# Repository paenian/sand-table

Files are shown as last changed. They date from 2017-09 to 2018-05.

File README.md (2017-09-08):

# sand-table

I'd like to make my own sand drawing table.

Main desired features:
G-code driven
hand-wheel drive as well

The initial drive idea is similar to the Maslow CNC, which is cable-driven polar
robot with two stepper motors.  Instead of using weights, I'll use constant-
force springs to keep the main carriage taut and driving.  The carriage will be
under the sand table, and moving a neodidlium magnet to drag a steel ball bearing
around.

I'd like it to be usable as a table, but also interactive - the easy way is a
handheld magnet puck that can steal the ball bearing and be used to draw directly;
also would like some direct-input hand wheels, and the ability to load new
drawings easily.  A good end-goal would be a self-hosted website where random
photos could be dropped, traced, parsed to gcode and drawn.

Most parts will be 3D printed.

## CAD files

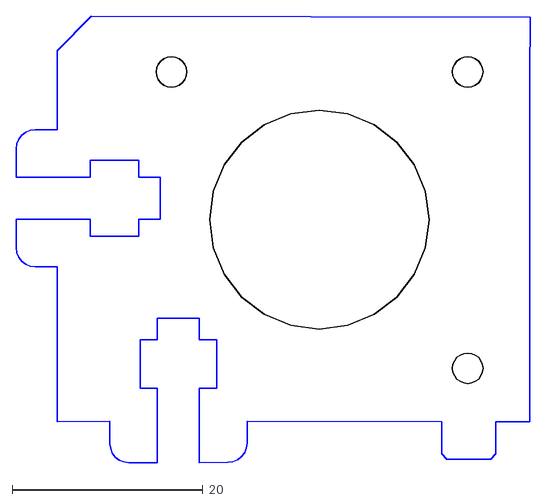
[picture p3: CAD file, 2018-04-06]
gcodes/y_motor_mount.dxf
53.8 x 46.7

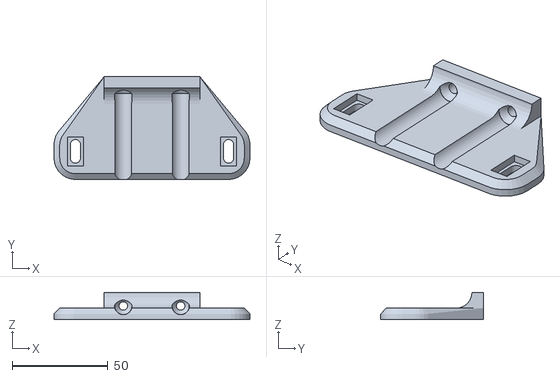
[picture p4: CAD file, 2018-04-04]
hardware/crossbot_stls/mount_brace.stl
102.4 x 53.6 x 14.2

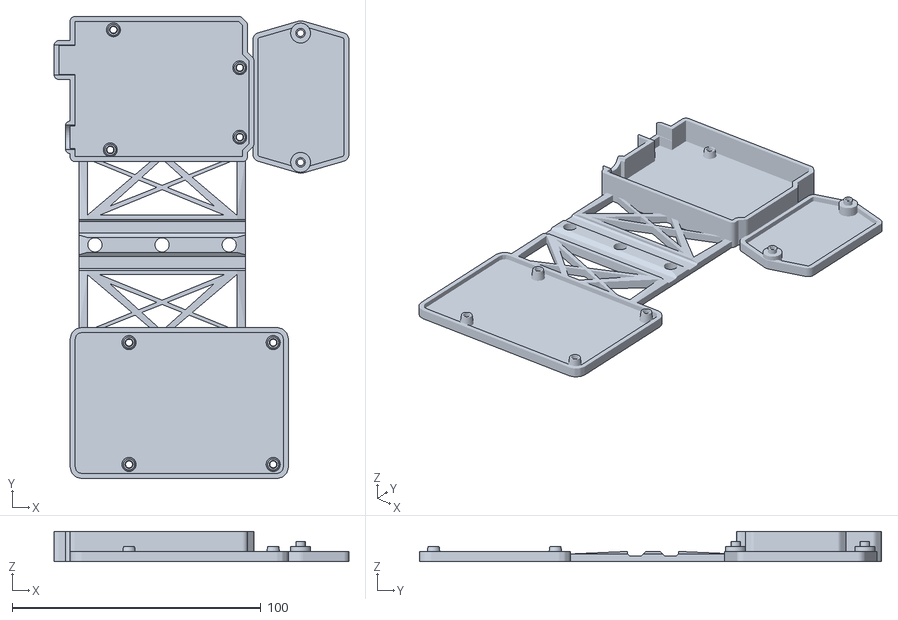
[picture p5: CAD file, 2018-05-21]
hardware/electronics_plate.stl
118.7 x 185.9 x 12.1

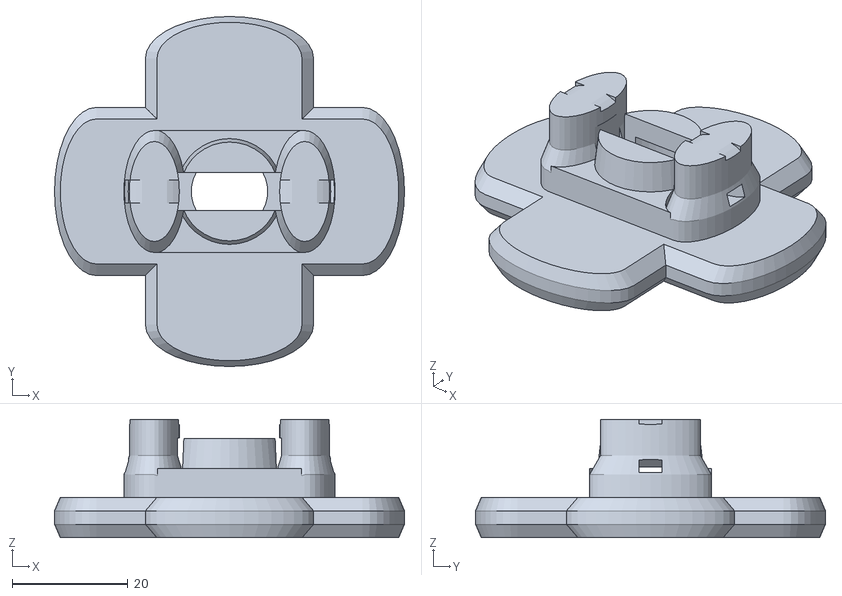
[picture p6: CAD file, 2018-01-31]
hardware/gravity_stls/magnet_mount_1-2.stl
60.5 x 60.5 x 20.5

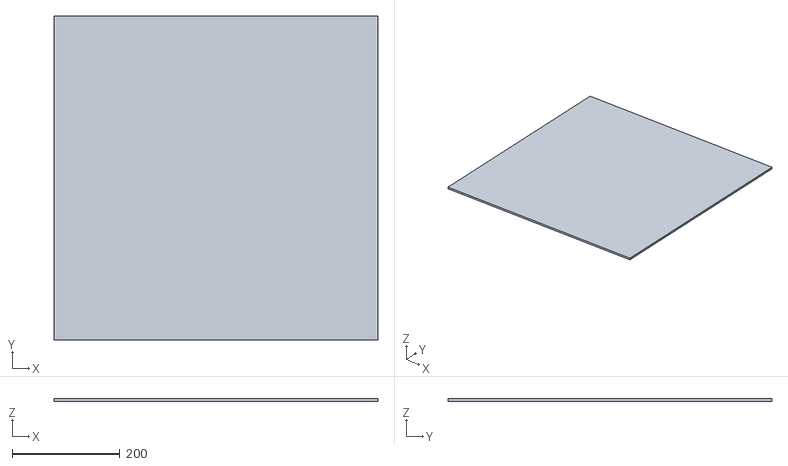
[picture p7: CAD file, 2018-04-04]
gcodes/clear.stl
600.0 x 600.0 x 5.00

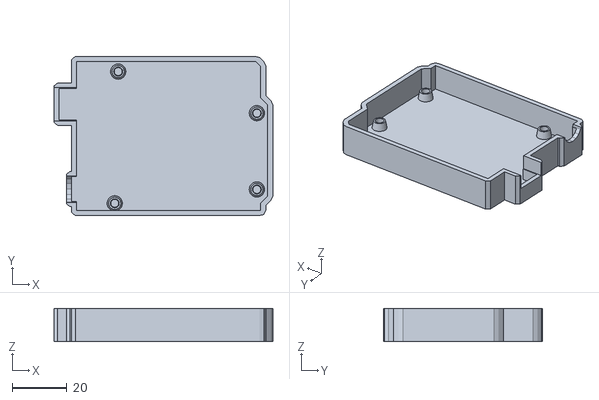
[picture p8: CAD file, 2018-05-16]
hardware/arduino_sled.stl
80.2 x 58.3 x 12.1

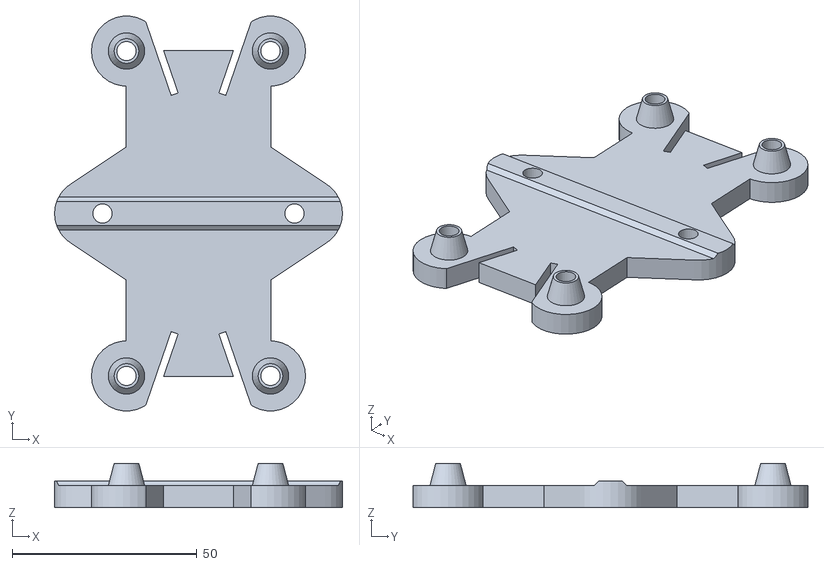
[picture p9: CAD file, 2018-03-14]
hardware/crossbot_stls/beam_carriage.stl
78.0 x 106.9 x 12.0

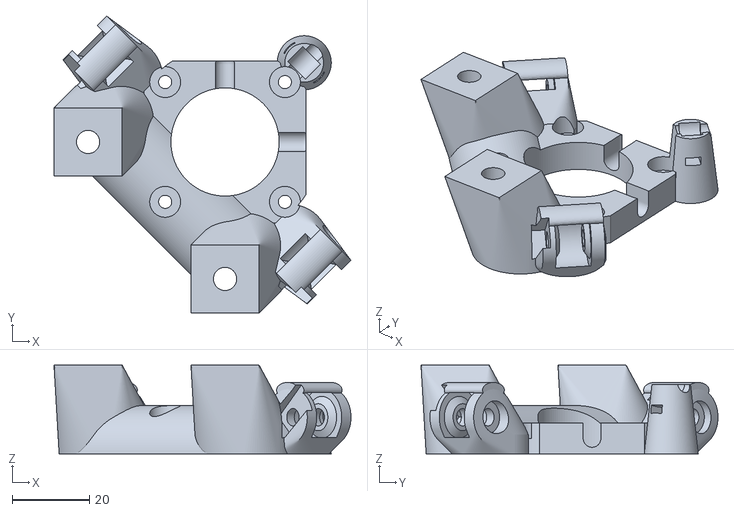
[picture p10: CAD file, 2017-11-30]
hardware/gravity_stls/gravity_leg_motor.stl
76.9 x 76.9 x 23.0

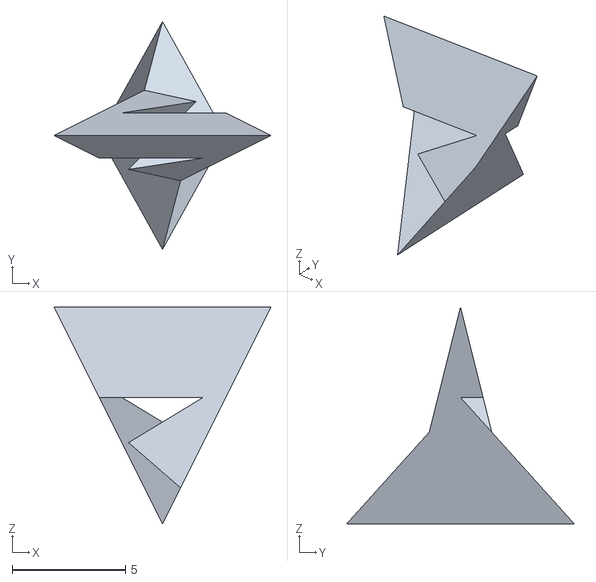
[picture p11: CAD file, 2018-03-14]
software/inkscape/share/extensions/Poly3DObjects/szilassi.obj
9.60 x 10.1 x 9.60

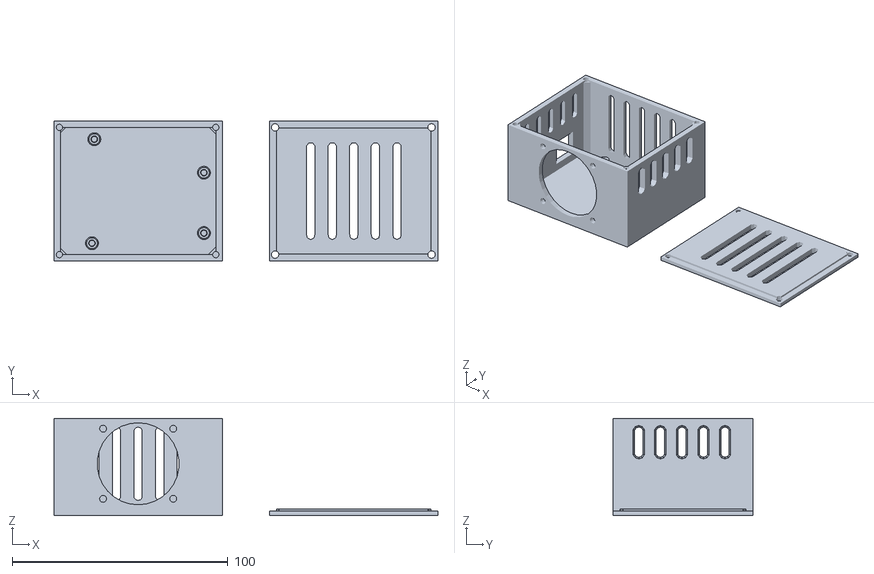
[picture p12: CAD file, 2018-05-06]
hardware/arduino_mount.stl
178.0 x 65.0 x 45.0

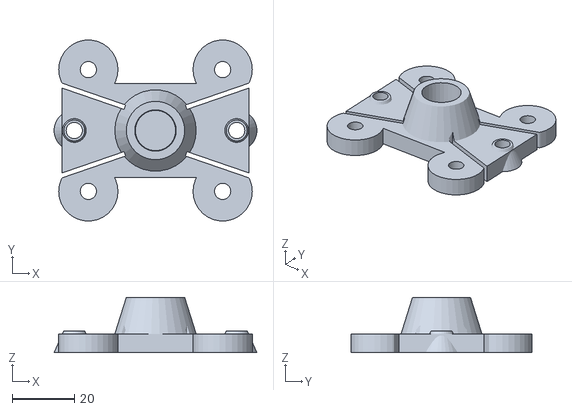
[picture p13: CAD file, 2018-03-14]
hardware/crossbot_stls/magnet_carriage.stl
65.0 x 57.9 x 17.7

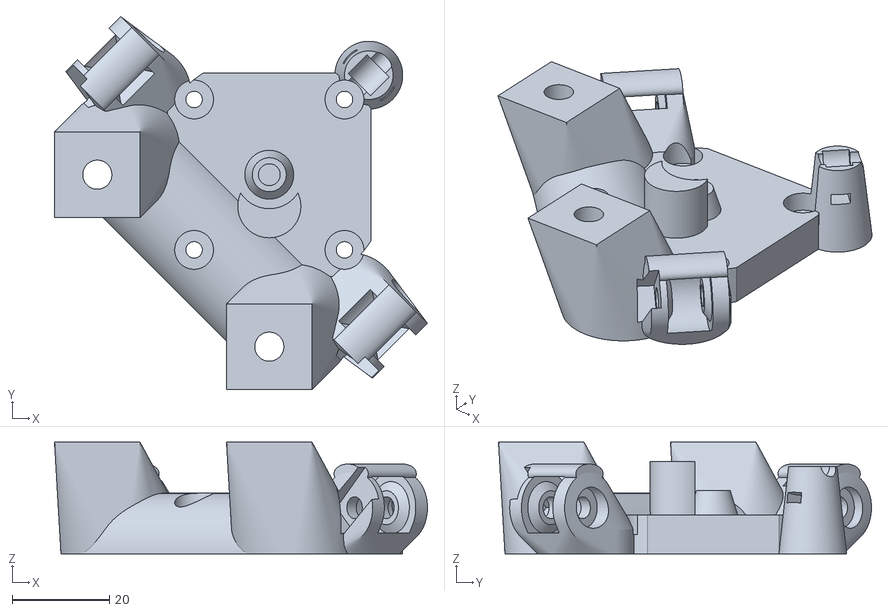
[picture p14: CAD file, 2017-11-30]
hardware/gravity_stls/gravity_leg_idler.stl
76.9 x 76.9 x 23.0

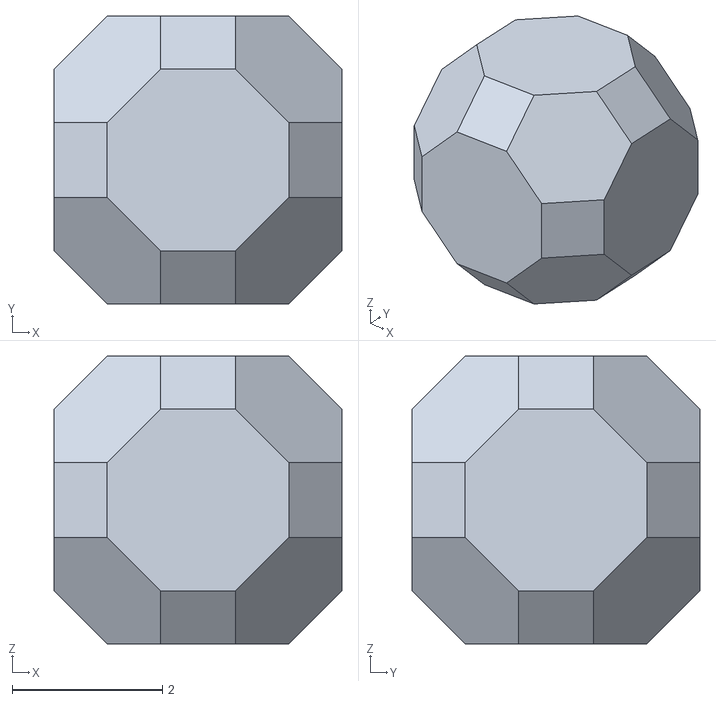
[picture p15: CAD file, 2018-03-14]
software/inkscape/share/extensions/Poly3DObjects/great_rhombicuboct.obj
3.83 x 3.83 x 3.83

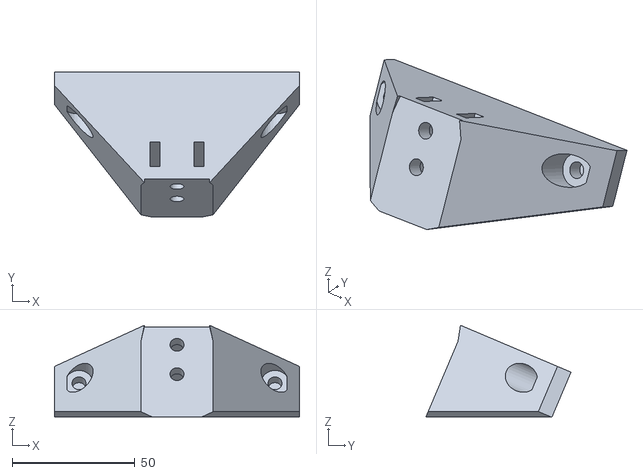
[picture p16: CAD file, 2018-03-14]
hardware/crossbot_stls/base_beam_mount_motor.stl
100.0 x 59.2 x 37.3

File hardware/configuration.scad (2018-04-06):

in = 25.4;
beam = 20;

wall = 6;   //beefy carriages


spacer_height = 6; 

//this is for the big v-wheels
wheel_thick = 10.23;
wheel_rad = 23.9/2;
wheel_eff_rad = 19/2;   //radius sticking out of the v-slot

/*
//this is for the mini v-wheels
wheel_thick = 8.8;
wheel_rad = 15.23/2;
wheel_eff_rad = 11/2;   //radius sticking out of the v-slot
*/

main_beam_length = 500;
cross_beam_length = 500;

//height of the stack!
//the magnet is at zero, so nothing sticks up above the Z plane.
magnet_height = in/2;
magnet_rad = in/4;
carriage_clearance = wall + (wheel_thick/2+spacer_height)-beam/2;
echo(carriage_clearance);
                //magnet         this beam  X carriage             x beam
y_beam_height = -magnet_height - beam/2 -   carriage_clearance -   beam - carriage_clearance;
x_beam_height = -magnet_height - beam/2 - carriage_clearance;
magnet_carriage_height = -magnet_height-wall;
beam_carriage_height = -magnet_height-carriage_clearance-beam-wall;

//idler RANDOM NUMBERS
idler_rad = 9;
idler_flange_rad = 11;
idler_flange_thick = 1.5;
idler_height = 12;

//pulley RANDOM NUMBERS
pulley_rad = 9;
pulley_flange_rad = 11;
pulley_flange_thick = 1.5;
pulley_base_rad = 12;
pulley_base_thick = 10;
pulley_height = 18;


//screws et al
m5_rad = 5/2+.15;
m5_nut_rad = 8.79/2+.25;

belt_thick = 1.5;
belt_height = 6;




module beam(length = 20, center=true){
    beam_wall = 1.8;
    beam_center_rad = 4.2/2+.1;
    
    difference(){
        cube([beam, beam, length], center=center);
        
        //center hole
        translate([0,0,-.1]) cylinder(r=beam_center_rad, h=length+1, center=center, $fs=1);
        
        //inside
        translate([0,0,-.1]) difference(){
            cube([beam-beam_wall*2,beam-beam_wall*2,length+1], center=center);
            
            //center
            cube([7,7,length+2], center=true);
            //cross walls
            for(i=[45:90:179]) rotate([0,0,i]) {
                cube([1.5, 19.75, length+1], center=true);
            }
            
            //corners
            for(i=[0:90:359]) rotate([0,0,i]) translate([beam/2, beam/2,0]) {
                difference(){
                    cube([(1.8+1.07+1.75)*2, (1.8+1.07+1.75)*2, length+1], center=true);
                    cube([(1.8+1.75)*2, (1.8+1.75)*2, length+1], center=true);
                }
            }
        }
        
        //v slot channel
        for(i=[0:90:359]) rotate([0,0,i]) translate([beam/2, 0,0]) {
            rotate([0,0,45]) cube([6.5,6.5,length+2], center=true);
        }
        
        //chamfer the corners
        for(i=[0:90:359]) rotate([0,0,i]) translate([beam/2, beam/2,0]) {
            rotate([0,0,45]) cube([1,1,length+2], center=true);
        }
    }
}

module pulley(solid = 1){
    if(solid == 1){
        difference(){
            union(){
                cylinder(r=pulley_rad, h=pulley_height, center=true);
                translate([0,0,pulley_height/2-pulley_flange_thick/2])
                    cylinder(r=pulley_flange_rad, h=pulley_flange_thick, center=true);
            
                translate([0,0,-pulley_height/2+pulley_base_thick/2]) cylinder(r=pulley_base_rad, h=pulley_base_thick, center=true);
            }
        
            cylinder(r=m5_rad, h=pulley_height+1, center=true);
        }
    }else{
        cylinder(r=m5_rad, h=idler_height*5, center=true);
    }
}

module idler(solid = 1){
    if(solid == 1){
        difference(){
            union(){
                cylinder(r=idler_rad, h=idler_height, center=true);
                for(i=[0,1]) mirror([0,0,i]) translate([0,0,idler_height/2-idler_flange_thick/2]){
                    cylinder(r=idler_flange_rad, h=idler_flange_thick, center=true);
                }
            
                //ghost in some belts
                for(i=[0,1]) mirror([0,i,0]) translate([0,idler_rad+belt_thick/2,0]){
                    %cube([200,belt_thick,belt_height], center=true);
                }
            }
        
            cylinder(r=m5_rad, h=idler_height+1, center=true);
        }
    }else{
        cylinder(r=m5_rad, h=idler_height*5, center=true);
    }
}

module wheel(solid = 1){
    if(solid == 1){
        difference(){
            hull(){
                cylinder(r=wheel_rad, h=wheel_thick/3, center=true);
                cylinder(r=wheel_rad-wheel_thick/3, h=wheel_thick, center=true);
            }
        
            cylinder(r=m5_rad, h=idler_height+1, center=true);
        }
    }else{
        cylinder(r=m5_rad, h=idler_height*3, center=true);
    }
}

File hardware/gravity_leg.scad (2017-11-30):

in = 25.4;

fs = .3;

$fa = 3;    //sets the angle low enough that $fs is dominant
$fs = fs;    //the smallest edge is this long - with a .4mm nozzle, the facets should be undetectable for printing, but we keep it high for modeling faster.

motor_w = 42;
motor_h = 30;
motor_rad = 50/2;
motor_bump_rad = 26/2+1;
motor_bump_height = 2;
motor_shaft_rad = 4/2+.25;
motor_shaft_len = 22;
motor_screw_sep = 31;
motor_screw_rad = 3.4/2;
motor_screw_cap_rad = 8/2;
motor_screw_len = 10;

pulley_rad = 40/(2*3.14159)+.25; 
pulley_height = 19;
pulley_base_height = 7;
pulley_base_rad = 11-.25;
pulley_nut_rad = 7;
pulley_nut_thick = 3;

hairpin_base_width = 50;
hairpin_base_height = 127;
hairpin_base_thick = 3;
hairpin_leg_rad = 3/8*in/2;
hairpin_x_offset = 88;
hairpin_y_offset = 18;
hairpin_leg_extend = hairpin_base_width;
hairpin_hole_inset = 9;
hairpin_hole_1 = in*1.75;
hairpin_hole_2 = hairpin_base_height-hairpin_hole_inset;
hairpin_hole_rad = 5/2;
hairpin_hole_cap_rad = 11/2;

v_pulley_thick = 6;
v_pulley_rad = 9/2;
v_pulley_center_rad = 7/2;
v_pulley_flange_rad = 13/2;
v_pulley_edge_thick = 1;

screw_rad = 4/2+.25;
screw_cap_rad = 8/2+.25;
screw_len = 16;
nut_rad = 10/2+.25;
nut_height = 3.25;

spacer_len = 5;
spacer_rad = 6/2+.25;
spacer_wall = 1.125;

string_height = pulley_base_height+(pulley_height-pulley_base_height)/2+motor_bump_height/2;
string_rad = 1;


wall = 4;
motor_offset = -hairpin_base_width/2+hairpin_hole_1;
leg_lift = 23;

%motor();
%translate([-motor_offset,-motor_offset,leg_lift+hairpin_base_thick]) hairpin_leg();


!gravity_leg();
gravity_leg(motor=false);
string_pulley();
*weight_claw(pulley=true);

module weight_claw(h=14, angle = 30, pulley=true){
    weight_rad = in*2/2-.25;
    belt_rad = 11;
    
    difference(){
        union(){
            rotate_extrude(){
                translate([weight_rad,0,0]) circle(r=belt_rad);
            }
            
            if(pulley == true){
                hull(){
                    translate([-weight_rad-belt_rad*0,0,0]) rotate([90,0,0]) cylinder(r=belt_rad, h=screw_len, center=true);
                    translate([-weight_rad-belt_rad*1,0,0]) scale([1,1,1.4]) rotate([90,0,0]) cylinder(r=v_pulley_rad+1, h=screw_len, center=true);
                }
            }
        }
        
        
        sphere(r=weight_rad);
        
        //cut out a chunk
        difference(){
            for(i=[angle/2,-angle/2]) rotate([0,0,i-45]) translate([0,0,-50]) cube([100,100,100]);
            
            for(i=[angle/2,-90-angle/2]) rotate([0,0,i-45+90]) translate([weight_rad,0,0]) sphere(r=belt_rad);
        }
        
        //add the pulley
        if(pulley == true){
            translate([-weight_rad-belt_rad*1,0,0]) rotate([90,0,0]) {
                screw_pack(extend = 11);
                v_pulley(solid=-1);
                %v_pulley(solid=1);
                
            }
        }
        
        //flatten top/bottom
        for(i=[0,1]) mirror([0,0,i]) translate([0,0,100+h/2]) cube([200,200,200], center=true);
    }
}

module gravity_leg(height = leg_lift, motor=true, leg=true){
    base_thick = wall+4;
    v_pulley_height = string_height-v_pulley_thick/2+string_rad*2;
    difference(){
        union(){
            //baseplate - everything mounts here
            translate([0,0,wall/2+2]) motor_body(motor_h=base_thick, motor_bump_height = wall*5, bump=motor);
            
            if(motor == false){
                //draw the v-pulley in
                %translate([0,0,v_pulley_height+v_pulley_thick/2]) v_pulley(solid=1);
                
                //add a bump for the pulley to sit on
                cylinder(r1=v_pulley_center_rad+wall, r2=v_pulley_center_rad, h=v_pulley_height);
                
                //and a guide for the string
                difference(){
                    translate([0,-v_pulley_flange_rad,0]) cylinder(r=v_pulley_flange_rad, h=v_pulley_height+v_pulley_thick);
                    cylinder(r=v_pulley_flange_rad+string_rad/2, h=height+1);
                }
            }else{
                //guide for string around the pulley?
            }
            
            //mount it to the leg
            if(leg == true){
                leg_mount(solid=1, h=height, offset = hairpin_hole_1-hairpin_hole_inset);
            }else{
                //todo: spring mount
            }
            
            //mount the weight pulley and attachment
            weight_mount();
            
            //guide for the string - zip tie in a spacer
            guide_spacer(solid=1);
        }
        
        //attach the motor
        motor_holes(motor_h=wall, motor_bump_height = wall*5, bump=motor, shaft=motor);
        
        if(motor == false){
            //mount the pulley
            translate([0,0,8]){
                translate([0,0,-v_pulley_thick+nut_height+.2]) cylinder(r=screw_rad, h=screw_len);
                hull(){
                    translate([0,0,-v_pulley_thick]) cylinder(r1=nut_rad+.25, r2=nut_rad, h=nut_height, $fn=4);
                    translate([0,0,-v_pulley_thick-8]) cylinder(r1=nut_rad+1, r2=nut_rad+.25, h=8.1, $fn=4);
                }
            }
        }
        
        //make some slots so we can actually attach the pulley
        if(motor == true){
            rad = 2.5;
            for(i=[0,90]) rotate([0,0,i]) translate([0,0,base_thick/2]) hull(){
                cylinder(r=rad, h=10);
                sphere(r=rad);
                
                translate([20,0,0]){
                    cylinder(r=rad, h=10);
                    sphere(r=rad);
                }
            }
        }
        
        //mount the weight pulley and attachment
        weight_mount(solid=-1);
        
        //screwholes for the leg mount
        leg_mount(solid=0, h=height, offset = hairpin_hole_1-hairpin_hole_inset);
        
        //guide for the string - zip tie in a spacer
        guide_spacer(solid=0);
    }
}

module weight_mount(solid=1){
    off = motor_screw_sep/2+11;
    
    translate([-pulley_rad/sqrt(2),-pulley_rad/sqrt(2),0])
    for(i=[0,1]) rotate([0,0,45]) mirror([0,i,0]) rotate([0,0,-45]) if(solid==1){
        union(){
            hull(){
                translate([off-5,-off+5,0]) cylinder(r=10, h=wall+1);
                translate([off,-off,string_height-v_pulley_rad]) rotate([0,0,45]) rotate([0,90,0]) {
                    cylinder(r=v_pulley_flange_rad+.75, h=screw_len, center=true);
                    
                }
            }
            translate([off,-off,string_height-v_pulley_rad-1.5]) rotate([0,0,45]) rotate([0,90,0]) translate([-2-v_pulley_flange_rad,0,0])  scale([1,2,1]) rotate([0,0,45]) cylinder(r=2, h=screw_len, center=true);
            
        }
    }else{
        translate([off,-off,string_height-v_pulley_rad]) rotate([0,0,45]) rotate([0,90,0]) {
            screw_pack(extend_nut=true);
            v_pulley(solid=-1);
            %translate([-v_pulley_rad-1,0,0]) rotate([90,0,0]) cylinder(r=string_rad+.1, h=30, center=true);
            %v_pulley(solid=1);
        }
    }
}

module v_pulley(solid=-1, edge=1.5){
    if(solid == 1){
        for(i=[0,1]) mirror([0,0,i]) {
            cylinder(r1=v_pulley_rad, r2=v_pulley_flange_rad, h=v_pulley_thick/2-v_pulley_edge_thick);
            translate([0,0,v_pulley_thick/2-v_pulley_edge_thick]) cylinder(r=v_pulley_flange_rad, h=v_pulley_edge_thick);
        }
    }else{
        difference(){
            cylinder(r=v_pulley_flange_rad+1, h=v_pulley_thick+edge*2.1, center=true);
            for(i=[0,1]) mirror([0,0,i]) translate([0,0,-v_pulley_thick/2-edge*1.1])
                cylinder(r1=v_pulley_center_rad+2, r2=v_pulley_center_rad, h=edge-.125);
        }
    }
    
    
}

module screw_pack(extend = 0, extend_nut=false){
    screw_cap_len = 4;
    cylinder(r=screw_rad, h=screw_len+screw_cap_len, center=true);
    translate([0,0,screw_len/2+extend/2]) cylinder(r=screw_cap_rad, h=screw_cap_len+extend, center=true);
    hull(){
        translate([0,0,-screw_len/2-extend/2]) cylinder(r1=nut_rad+.125, r2=nut_rad, h=screw_cap_len+extend, center=true, $fn=4);
        if(extend_nut == true){
            translate([-5,-5,-screw_len/2-extend/2]) cylinder(r1=nut_rad+.125, r2=nut_rad, h=screw_cap_len+extend, center=true, $fn=4);
        }
    }
}

module guide_spacer(solid=1){
    h = string_height+string_rad*4;
    off = motor_screw_sep/2+5;
    translate([off, off, 0])
    if(solid == 1){
        hull(){
            cylinder(r1=spacer_len+2, r2=spacer_len, h=h);
        }
    }else{
        //spacer
        translate([0,0,h]) rotate([0,0,45]) rotate([0,90,0]) {
            cylinder(r=spacer_rad, h=spacer_len+.5, center=true);
            cylinder(r=spacer_rad-spacer_wall, h=spacer_len*3, center=true);
        }
        
        //zip tie it in
        translate([0,0,h]) rotate([0,0,45]) scale([1,2,1]) rotate([0,90,0]) rotate_extrude(){
            translate([7,0,0]) square([2,4], center=true);
        }
    }
}
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

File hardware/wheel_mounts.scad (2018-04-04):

in = 25.4;

axle_rad = 5/16*in/2+.5;
axle_lift = 4*in;
length = 3*in;

wall = 8;
lip_inset = 2;


rotate([90,0,0]) boat_wheels();
//rotate([90,0,0]) mirror([1,0,0]) boat_wheels();


module boat_wheels(){
    difference(){
        union(){
            //axle
            translate([0,0,axle_lift]){
                rotate([90,0,0]) cylinder(r=axle_rad+wall, h=wall, center=true);
                rotate([90,0,0]) translate([0,0,wall-.1]) cylinder(r1=axle_rad+wall, r2=axle_rad+wall/2, h=wall+.1, center=true);
            }
            
            //attach bar
            hull(){
                rotate([90,0,0]) cylinder(r=axle_rad+wall, h=wall, center=true);
                rotate([90,0,0]) translate([0,0,wall-.1]) cylinder(r1=axle_rad+wall, r2=axle_rad+wall/2, h=wall+.1, center=true);
                
                translate([length,0,0]){
                    rotate([90,0,0]) cylinder(r=axle_rad+wall, h=wall, center=true);
                    rotate([90,0,0]) translate([0,0,wall-.1]) cylinder(r1=axle_rad+wall, r2=axle_rad+wall/2, h=wall+.1, center=true);
                }
            }
            
            //connect up the axle
            hull(){
                translate([0,0,axle_lift]){
                    rotate([90,0,0]) cylinder(r=axle_rad+wall, h=wall, center=true);
                    rotate([90,0,0]) translate([0,0,wall-.1]) cylinder(r1=axle_rad+wall, r2=axle_rad+wall/2, h=wall+.1, center=true);
                }
                
                rotate([90,0,0]) cylinder(r=axle_rad+wall, h=wall, center=true);
                rotate([90,0,0]) translate([0,0,wall-.1]) cylinder(r1=axle_rad+wall, r2=axle_rad+wall/2, h=wall+.1, center=true);
            }
            
            hull(){
                translate([0,0,axle_lift]){
                    rotate([90,0,0]) cylinder(r=axle_rad+wall, h=wall, center=true);
                    rotate([90,0,0]) translate([0,0,wall-.1]) cylinder(r1=axle_rad+wall, r2=axle_rad+wall/2, h=wall+.1, center=true);
                }
                
                translate([length,0,0]) {
                    rotate([90,0,0]) cylinder(r=axle_rad+wall, h=wall, center=true);
                    rotate([90,0,0]) translate([0,0,wall-.1]) cylinder(r1=axle_rad+wall, r2=axle_rad+wall/2, h=wall+.1, center=true);
                }
            }
        }
        
        //axle holder
        translate([0,0,axle_lift]){
            rotate([90,0,0]) cylinder(r=axle_rad, h=50, center=true);
            rotate([90,0,0]) translate([0,0,-wall*1.5]) cylinder(r2=10, r1=20, h=10, $fn=29);
        }
        
        //cut out to attach
        translate([0,wall/2+wall-lip_inset,0]) cube([500,wall*2,(axle_rad+wall*2)*2], center=true);
        
        //some screwholes
        for(i=[0:length/2:length]) translate([i,0,0]) {
            rotate([-90,0,0]) cylinder(r=2.6, h=50, center=true, $fn=29);
            rotate([90,0,0]) translate([0,0,wall/2]) cylinder(r1=2.6, r2=9/2, h=4.1, $fn=29);
            rotate([90,0,0]) translate([0,0,wall/2+4]) cylinder(r=9/2, h=10, $fn=29);
        }
    }
}

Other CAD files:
software/inkscape/share/extensions/Poly3DObjects/rh_axes.obj
hardware/glass_clamp.stl
hardware/gravity_stls/string_pulley.stl
software/inkscape/share/extensions/Poly3DObjects/small_rhombicuboct.obj
hardware/crossbot.scad
hardware/PM_UNO_base_fan_holder.stl
hardware/PM_uno_mount_fan_mod.stl
hardware/cross_idler.stl
hardware/cross_motor.stl
hardware/crossbot_stls/base_beam_mount.stl
hardware/crossbot_stls/double_idler.stl
hardware/crossbot_stls/motor_beam_mount.stl
hardware/crossbot_stls/motor_mount.stl
hardware/crossbot_stls/offset_motor_mount.stl
hardware/electronics_plate.scad
hardware/glass_clamp_base.stl
hardware/glass_clamp_lever.stl
hardware/glass_clamps.scad
hardware/gravity_stls/belt_clamp.stl
hardware/gravity_stls/belt_pulley.stl
hardware/gravity_stls/drill_guide.stl
hardware/gravity_stls/half_in_magnet_mount.stl
hardware/gravity_stls/idler_corner.stl
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

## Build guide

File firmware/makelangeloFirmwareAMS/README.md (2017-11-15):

Testing with the Makelangelo firmware on the Adafruit motor shield.

Couldn't find documentation...

##MCODES
M17: Engage motors
M18: Disengage motors
M100: Show Help
M101: T### B### R### L### G### H### : process config
Top, Bottom, Right, Left, ?, ?

M114: Show current position

##GCODES
G0 & G1: Line Move
G2 & G3: Arc move
G4 S###: Pause ### seconds?
G20: Scale inches to CM
G21: Scale mm to cm
G59 X### Y### Z### : set tool offset
G90: Set Absolute Mode
G91: Set Relative Mode
G92 X### Y### Z### : Set Position

##DCODES
D0 (L|R)### : Move L or R motor ### distance.
D1 L### R### : Adjust spool diameter
D2 : Print pulley diameters
D3 : List SD Card Files
D4 <filename> : Draw file from SD
D5 : Print version number
D6 : set home position
D10 : Print Hardware Version Number

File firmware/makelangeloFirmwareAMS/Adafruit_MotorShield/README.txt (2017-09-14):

 This is the library for the Adafruit Motor Shield V2 for Arduino.
 It supports DC motors & Stepper motors with microstepping as well
 as stacking-support. It is *not* compatible with the V1 library!

 It will only work with https://www.adafruit.com/products/1483

 Adafruit invests time and resources providing this open
 source code, please support Adafruit and open-source hardware
 by purchasing products from Adafruit!

 Written by Limor Fried/Ladyada for Adafruit Industries.
 BSD license, check license.txt for more information.
 All text above must be included in any redistribution.

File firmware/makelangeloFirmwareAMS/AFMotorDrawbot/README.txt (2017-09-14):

This is the August 12, 2009 Adafruit Motor shield firmware with basic Microstepping support. Works with all Arduinos and the Mega

For more information on the shield, please visit http://www.ladyada.net/make/mshield/

To install, click DOWNLOAD SOURCE in the top right corner, and see our tutorial at http://www.ladyada.net/library/arduino/libraries.html on Arduino Library installation

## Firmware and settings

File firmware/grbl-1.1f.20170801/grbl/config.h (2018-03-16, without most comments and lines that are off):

#define config_h
#include "grbl.h" // For Arduino IDE compatibility.
#define DEFAULTS_GENERIC
#define CPU_MAP_ATMEGA328P // Arduino Uno CPU
#define BAUD_RATE 115200
#define CMD_RESET 0x18 // ctrl-x.
#define CMD_STATUS_REPORT '?'
#define CMD_CYCLE_START '~'
#define CMD_FEED_HOLD '!'
#define CMD_SAFETY_DOOR 0x84
#define CMD_JOG_CANCEL  0x85
#define CMD_DEBUG_REPORT 0x86 // Only when DEBUG enabled, sends debug report in '{}' braces.
#define CMD_FEED_OVR_RESET 0x90         // Restores feed override value to 100%.
#define CMD_FEED_OVR_COARSE_PLUS 0x91
#define CMD_FEED_OVR_COARSE_MINUS 0x92
#define CMD_FEED_OVR_FINE_PLUS  0x93
#define CMD_FEED_OVR_FINE_MINUS  0x94
#define CMD_RAPID_OVR_RESET 0x95        // Restores rapid override value to 100%.
#define CMD_RAPID_OVR_MEDIUM 0x96
#define CMD_RAPID_OVR_LOW 0x97
#define CMD_SPINDLE_OVR_RESET 0x99      // Restores spindle override value to 100%.
#define CMD_SPINDLE_OVR_COARSE_PLUS 0x9A
#define CMD_SPINDLE_OVR_COARSE_MINUS 0x9B
#define CMD_SPINDLE_OVR_FINE_PLUS 0x9C
#define CMD_SPINDLE_OVR_FINE_MINUS 0x9D
#define CMD_SPINDLE_OVR_STOP 0x9E
#define CMD_COOLANT_FLOOD_OVR_TOGGLE 0xA0
#define CMD_COOLANT_MIST_OVR_TOGGLE 0xA1
#define HOMING_INIT_LOCK // Comment to disable
#define HOMING_CYCLE_0 ((1<<X_AXIS)|(1<<Y_AXIS))  // OPTIONAL: Then move X,Y at the same time.
#define N_HOMING_LOCATE_CYCLE 1 // Integer (1-128)
#define N_STARTUP_LINE 2 // Integer (1-2)
#define N_DECIMAL_COORDVALUE_INCH 4 // Coordinate or position value in inches
#define N_DECIMAL_COORDVALUE_MM   3 // Coordinate or position value in mm
#define N_DECIMAL_RATEVALUE_INCH  1 // Rate or velocity value in in/min
#define N_DECIMAL_RATEVALUE_MM    0 // Rate or velocity value in mm/min
#define N_DECIMAL_SETTINGVALUE    3 // Decimals for floating point setting values
#define N_DECIMAL_RPMVALUE        0 // RPM value in rotations per min.
#define MESSAGE_PROBE_COORDINATES // Enabled by default. Comment to disable.
#define SAFETY_DOOR_SPINDLE_DELAY 4.0 // Float (seconds)
#define SAFETY_DOOR_COOLANT_DELAY 1.0 // Float (seconds)
#define CHECK_LIMITS_AT_INIT
#define DEFAULT_FEED_OVERRIDE           100 // 100%. Don't change this value.
#define MAX_FEED_RATE_OVERRIDE          200 // Percent of programmed feed rate (100-255). Usually 120% or 200%
#define MIN_FEED_RATE_OVERRIDE           10 // Percent of programmed feed rate (1-100). Usually 50% or 1%
#define FEED_OVERRIDE_COARSE_INCREMENT   10 // (1-99). Usually 10%.
#define FEED_OVERRIDE_FINE_INCREMENT      1 // (1-99). Usually 1%.
#define DEFAULT_RAPID_OVERRIDE  100 // 100%. Don't change this value.
#define RAPID_OVERRIDE_MEDIUM    50 // Percent of rapid (1-99). Usually 50%.
#define RAPID_OVERRIDE_LOW       25 // Percent of rapid (1-99). Usually 25%.
#define DEFAULT_SPINDLE_SPEED_OVERRIDE    100 // 100%. Don't change this value.
#define MAX_SPINDLE_SPEED_OVERRIDE        200 // Percent of programmed spindle speed (100-255). Usually 200%.
#define MIN_SPINDLE_SPEED_OVERRIDE         10 // Percent of programmed spindle speed (1-100). Usually 10%.
#define SPINDLE_OVERRIDE_COARSE_INCREMENT  10 // (1-99). Usually 10%.
#define SPINDLE_OVERRIDE_FINE_INCREMENT     1 // (1-99). Usually 1%.
#define RESTORE_OVERRIDES_AFTER_PROGRAM_END // Default enabled. Comment to disable.
#define REPORT_FIELD_BUFFER_STATE // Default enabled. Comment to disable.
#define REPORT_FIELD_PIN_STATE // Default enabled. Comment to disable.
#define REPORT_FIELD_CURRENT_FEED_SPEED // Default enabled. Comment to disable.
#define REPORT_FIELD_WORK_COORD_OFFSET // Default enabled. Comment to disable.
#define REPORT_FIELD_OVERRIDES // Default enabled. Comment to disable.
#define REPORT_FIELD_LINE_NUMBERS // Default enabled. Comment to disable.
#define REPORT_OVR_REFRESH_BUSY_COUNT 20  // (1-255)
#define REPORT_OVR_REFRESH_IDLE_COUNT 10  // (1-255) Must be less than or equal to the busy count
#define REPORT_WCO_REFRESH_BUSY_COUNT 30  // (2-255)
#define REPORT_WCO_REFRESH_IDLE_COUNT 10  // (2-255) Must be less than or equal to the busy count
#define ACCELERATION_TICKS_PER_SECOND 100
#define ADAPTIVE_MULTI_AXIS_STEP_SMOOTHING  // Default enabled. Comment to disable.
#define TOOL_LENGTH_OFFSET_AXIS Z_AXIS // Default z-axis. Valid values are X_AXIS, Y_AXIS, or Z_AXIS.
#define VARIABLE_SPINDLE // Default enabled. Comment to disable.
#define MINIMUM_JUNCTION_SPEED 0.0 // (mm/min)
#define MINIMUM_FEED_RATE 1.0 // (mm/min)
#define N_ARC_CORRECTION 12 // Integer (1-255)
#define ARC_ANGULAR_TRAVEL_EPSILON 5E-7 // Float (radians)
#define DWELL_TIME_STEP 50 // Integer (1-255) (milliseconds)
#define ENABLE_RESTORE_EEPROM_WIPE_ALL         // '$RST=*' Default enabled. Comment to disable.
#define ENABLE_RESTORE_EEPROM_DEFAULT_SETTINGS // '$RST=$' Default enabled. Comment to disable.
#define ENABLE_RESTORE_EEPROM_CLEAR_PARAMETERS // '$RST=#' Default enabled. Comment to disable.
#define ENABLE_BUILD_INFO_WRITE_COMMAND // '$I=' Default enabled. Comment to disable.
#define FORCE_BUFFER_SYNC_DURING_EEPROM_WRITE // Default enabled. Comment to disable.
#define FORCE_BUFFER_SYNC_DURING_WCO_CHANGE // Default enabled. Comment to disable.
#define PARKING_AXIS Z_AXIS // Define which axis that performs the parking motion
#define PARKING_TARGET -5.0 // Parking axis target. In mm, as machine coordinate [-max_travel,0].
#define PARKING_RATE 500.0 // Parking fast rate after pull-out in mm/min.
#define PARKING_PULLOUT_RATE 100.0 // Pull-out/plunge slow feed rate in mm/min.
#define PARKING_PULLOUT_INCREMENT 5.0 // Spindle pull-out and plunge distance in mm. Incremental distance.
#define DISABLE_LASER_DURING_HOLD // Default enabled. Comment to disable.
#define N_PIECES 4  // Integer (1-4). Number of piecewise lines used in script solution.
#define RPM_MAX  11686.4  // Max RPM of model. $30 > RPM_MAX will be limited to RPM_MAX.
#define RPM_MIN  202.5    // Min RPM of model. $31 < RPM_MIN will be limited to RPM_MIN.
#define RPM_POINT12  6145.4  // Used N_PIECES >=2. Junction point between lines 1 and 2.
#define RPM_POINT23  9627.8  // Used N_PIECES >=3. Junction point between lines 2 and 3.
#define RPM_POINT34  10813.9 // Used N_PIECES = 4. Junction point between lines 3 and 4.
#define RPM_LINE_A1  3.197101e-03  // Used N_PIECES >=1. A and B constants of line 1.
#define RPM_LINE_B1  -3.526076e-1
#define RPM_LINE_A2  1.722950e-2   // Used N_PIECES >=2. A and B constants of line 2.
#define RPM_LINE_B2  8.588176e+01
#define RPM_LINE_A3  5.901518e-02  // Used N_PIECES >=3. A and B constants of line 3.
#define RPM_LINE_B3  4.881851e+02
#define RPM_LINE_A4  1.203413e-01  // Used N_PIECES = 4. A and B constants of line 4.
#define RPM_LINE_B4  1.151360e+03

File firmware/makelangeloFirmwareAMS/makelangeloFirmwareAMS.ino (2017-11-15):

//------------------------------------------------------------------------------
// Makelangelo polargraph robot firmware
// Supports Adafruit Motor Shield v1 and v2
// dan@marginallycelver.com 2012 feb 11
//------------------------------------------------------------------------------
// Copyright at end of file.  Please see
// http://www.github.com/MarginallyClever/Makelangelo for more information.


//------------------------------------------------------------------------------
// Sanity check
//------------------------------------------------------------------------------
#if defined(__AVR_ATmega2560__)
// wrong board type set
#error This code is not meant for Arduino MEGA or RUMBA boards.
#endif


//------------------------------------------------------------------------------
// CONSTANTS
//------------------------------------------------------------------------------
//#define MOTHERBOARD 1  // Adafruit Motor Shield 1
#define MOTHERBOARD 2  // Adafruit Motor Shield 2

#if MOTHERBOARD == 2
// stacked motor shields have different addresses. The default is 0x60
// 0x70 is the "all call" address - every shield will respond as one.
#define SHIELD_ADDRESS (0x60)
#endif

// machine style
#define POLARGRAPH2  // uncomment this line if you use a polargraph like the Makelangelo
//#define COREXY  // uncomment this line if you use a CoreXY setup.
//#define TRADITIONALXY  // uncomment this line if you use a traditional XY setup.

// Increase this number to see more output
#define VERBOSE         (3)

// Comment out this line to disable SD cards.
//#define USE_SD_CARD       (1)
// Comment out this line to disable findHome and limit switches
//#define USE_LIMIT_SWITCH  (1)


// which motor is on which pin?
#define M1_PIN          (1)
#define M2_PIN          (2)

// which limit switch is on which pin?
#define L_PIN           (3)
#define R_PIN           (5)

// Marginally Clever steppers are 400 steps per turn.
#define STEPPER_STEPS_PER_TURN    (200.0)
// We don't use microstepping on the AMS shield.
#define MICROSTEPPING_MULTIPLIER  (16.0)
#define STEPS_PER_TURN            (STEPPER_STEPS_PER_TURN*MICROSTEPPING_MULTIPLIER)


#define NUM_TOOLS  (6)


// *****************************************************************************
// *** Don't change the constants below unless you know what you're doing.   ***
// *****************************************************************************
#define MAKELANGELO_HARDWARE_VERSION 2

// switch sensitivity
#define SWITCH_HALF     (512)

// servo angles for pen control
#define PEN_UP_ANGLE    (90)
#define PEN_DOWN_ANGLE  (10)  // Some servos don't like 0 degrees
#define PEN_DELAY       (250)  // in ms

// NEMA17 are 200 steps (1.8 degrees) per turn.  If a spool is 0.8 diameter
// then it is 2.5132741228718345 circumference, and
// 2.5132741228718345 / 200 = 0.0125663706 thread moved each step.
// NEMA17 are rated up to 3000RPM.  Adafruit can handle >1000RPM.
// These numbers directly affect the maximum velocity.
//#define MAX_STEPS_S     (STEPS_PER_TURN*MAX_RPM/60.0)  // steps/s

#define MAX_FEEDRATE    (1000000.0)
#define MIN_FEEDRATE    (1.0) // steps / second

// for arc directions
#define ARC_CW          (1)
#define ARC_CCW         (-1)
// Arcs are split into many line segments.  How long are the segments?
#define MM_PER_SEGMENT  (10)

// Serial communication bitrate
#define BAUD            (57600)
// Maximum length of serial input message.
#define MAX_BUF         (64)

// servo pin differs based on device
#define SERVO_PIN1      (10)
#define SERVO_PIN2      (9)
#define SERVO_PIN       SERVO_PIN1  // switch if you want to use the other pin.  Thanks, Aleksey!

#define TIMEOUT_OK      (5000)  // 5s with no instruction? Make sure PC knows we are waiting.
#define TIMEOUT_MOTORS  (10000) // 10s with no command? Shut off motors.

#ifndef USE_SD_CARD
#define File int
#endif



#if MOTHERBOARD == 1
#define M1_ONESTEP(x)  m1.onestep(x)//,MICROSTEP)
#define M2_ONESTEP(x)  m2.onestep(x)//,MICROSTEP)
#endif
#if MOTHERBOARD == 2
#define M1_ONESTEP(x)  m1->onestep(x,MICROSTEP)
#define M2_ONESTEP(x)  m2->onestep(x,MICROSTEP)
#endif

//------------------------------------------------------------------------------
// EEPROM MEMORY MAP
//------------------------------------------------------------------------------
#define EEPROM_VERSION    7                   // Increment EEPROM_VERSION when adding new variables
#define ADDR_VERSION      0                   // 0..255 (1 byte)
#define ADDR_UUID        (ADDR_VERSION+1)     // long - 4 bytes
#define ADDR_PULLEY_DIA1 (ADDR_UUID+4)        // float - 4 bytes
#define ADDR_PULLEY_DIA2 (ADDR_PULLEY_DIA1+4) // float - 4 bytes
#define ADDR_LEFT        (ADDR_PULLEY_DIA2+4) // float - 4 bytes
#define ADDR_RIGHT       (ADDR_LEFT+4)        // float - 4 bytes
#define ADDR_TOP         (ADDR_RIGHT+4)       // float - 4 bytes
#define ADDR_BOTTOM      (ADDR_TOP+4)         // float - 4 bytes
#define ADDR_INVL        (ADDR_BOTTOM+4)      // bool - 1 byte
#define ADDR_INVR        (ADDR_INVL+1)        // bool - 1 byte
#define ADDR_HOMEX       (ADDR_INVR+1)        // float - 4 bytes
#define ADDR_HOMEY       (ADDR_HOMEX+4)       // float - 4 bytes


//------------------------------------------------------------------------------
// INCLUDES
//------------------------------------------------------------------------------
#if MOTHERBOARD == 1
#include <SPI.h>  // pkm fix for Arduino 1.5
// Adafruit motor driver library, optimized
#include "AFMotorDrawbot.h"
#endif

#if MOTHERBOARD == 2
#include <Wire.h>
#include <Adafruit_MotorShield.h>
#endif

// Default servo library
#include <Servo.h>

// SD card library
#ifdef USE_SD_CARD
#include <SD.h>
#endif

// Saving config
#include <EEPROM.h>
#include <Arduino.h>  // for type definitions

#include "Vector3.h"

//------------------------------------------------------------------------------
// VARIABLES
//------------------------------------------------------------------------------
#if MOTHERBOARD == 1
// Initialize Adafruit stepper controller
static AF_Stepper m1((int)STEPPER_STEPS_PER_TURN, M2_PIN);
static AF_Stepper m2((int)STEPPER_STEPS_PER_TURN, M1_PIN);
#endif
#if MOTHERBOARD == 2
// Initialize Adafruit stepper controller
Adafruit_MotorShield AFMS0 = Adafruit_MotorShield(SHIELD_ADDRESS);
Adafruit_StepperMotor *m1;
Adafruit_StepperMotor *m2;
#endif

static Servo s1;

// robot UID
int robot_uid=0;

// plotter limits
// all distances are relative to the calibration point of the plotter.
// (normally this is the center of the drawing area)
static float limit_top = 0;  // distance to top of drawing area.
static float limit_bottom = 0;  // Distance to bottom of drawing area.
static float limit_right = 0;  // Distance to right of drawing area.
static float limit_left = 0;  // Distance to left of drawing area.

static float homeX=0;
static float homeY=0;

// what are the motors called?
char m1d='L';
char m2d='R';

// motor inversions
char m1i = 1;
char m2i = 1;

// which way are the spools wound, relative to motor movement?
int M1_REEL_IN  = FORWARD;
int M1_REEL_OUT = BACKWARD;
int M2_REEL_IN  = FORWARD;
int M2_REEL_OUT = BACKWARD;

// calculate some numbers to help us find feed_rate
float pulleyDiameter = 4.0f/PI;  // cm
float threadPerStep = 4.0f/STEPS_PER_TURN;  // pulleyDiameter*PI/STEPS_PER_TURN

// plotter position.
static float posx;
static float posy;
static float posz;  // pen state
static float feed_rate=0;
static long step_delay;


// motor position
static long laststep1, laststep2;

static char absolute_mode=1;  // absolute or incremental programming mode?
static float mode_scale;   // mm or inches?
static char mode_name[3];


// Serial comm reception
static char serialBuffer[MAX_BUF+1];  // Serial buffer
static int sofar;               // Serial buffer progress
static long last_ready_time;    // prevent timeouts
static long last_cmd_time;      // motor disengage timeouts
static bool motors_engaged = false;

Vector3 tool_offset[NUM_TOOLS];
int current_tool=0;

long line_number;


//------------------------------------------------------------------------------
// METHODS
//------------------------------------------------------------------------------

//predeclarations
char loadVersion();
void sayVersionNumber();
void adjustInversions(int m1,int m2);
void loadPulleyDiameter();
void setHome(float x,float y);



//------------------------------------------------------------------------------
// calculate max velocity, threadperstep.
void adjustPulleyDiameter(float diameter1) {
  pulleyDiameter = diameter1;
  float PULLEY_CIRC = pulleyDiameter*PI;  // circumference
  threadPerStep = PULLEY_CIRC/STEPS_PER_TURN;  // thread per step

#if VERBOSE > 2
  Serial.print(F("PulleyDiameter = "));  Serial.println(pulleyDiameter,3);
  Serial.print(F("threadPerStep="));  Serial.println(threadPerStep,3);
#endif
}


//------------------------------------------------------------------------------
// returns angle of dy/dx as a value from 0...2PI
float atan3(float dy,float dx) {
  float a=atan2(dy,dx);
  if(a<0) a=(PI*2.0)+a;
  return a;
}


//------------------------------------------------------------------------------
char readSwitches() {
#ifdef USE_LIMIT_SWITCH
  // get the current switch state
  return ( (analogRead(L_PIN) < SWITCH_HALF) | (analogRead(R_PIN) < SWITCH_HALF) );
#else
  return 0;
#endif  // USE_LIMIT_SWITCH
}


//------------------------------------------------------------------------------
// feed rate is given in units/min and converted to cm/s
void setFeedRate(float v) {
  if(feed_rate==v) return;
  feed_rate=v;

  if(v > MAX_FEEDRATE) v = MAX_FEEDRATE;
  if(v < MIN_FEEDRATE) v = MIN_FEEDRATE;

  step_delay = 1000000.0 / v;
#if MOTHERBOARD == 1
  m1.setSpeed(v);
  m2.setSpeed(v);
#endif
#if MOTHERBOARD == 2
  m1->setSpeed(v);
  m2->setSpeed(v);
#endif

#if VERBOSE > 1
  Serial.print(F("feed_rate="));  Serial.println(feed_rate);
  Serial.print(F("step_delay="));  Serial.println(step_delay);
#endif
}


//------------------------------------------------------------------------------
void printFeedRate() {
  Serial.print(F("F"));
  Serial.println(feed_rate);
}


//------------------------------------------------------------------------------
// Change pen state.
void setPenAngle(int pen_angle) {
  if(posz!=pen_angle) {
#if VERBOSE > 1
    Serial.print(F("pen_angle="));  Serial.println(pen_angle);
#endif
    posz=pen_angle;

    if(posz<PEN_DOWN_ANGLE) posz=PEN_DOWN_ANGLE;
    if(posz>PEN_UP_ANGLE  ) posz=PEN_UP_ANGLE;

    s1.write( (int)posz );
    delay(PEN_DELAY);
  }
}


//------------------------------------------------------------------------------
// Inverse Kinematics - turns XY coordinates into lengths L1,L2
void IK(float x, float y, long &l1, long &l2) {
#ifdef COREXY
  l1 = lround((x+y) / threadPerStep);
  l2 = lround((x-y) / threadPerStep);
#endif
#ifdef TRADITIONALXY
  l1 = lround((x) / threadPerStep);
  l2 = lround((y) / threadPerStep);
#endif
#ifdef POLARGRAPH2
  // find length to M1
  float dy = y - limit_top;
  float dx = x - limit_left;
  l1 = lround( sqrt(dx*dx+dy*dy) / threadPerStep );
  // find length to M2
  dx = limit_right - x;
  l2 = lround( sqrt(dx*dx+dy*dy) / threadPerStep );
#endif
}


//------------------------------------------------------------------------------
// Forward Kinematics - turns L1,L2 lengths into XY coordinates
// use law of cosines: theta = acos((a*a+b*b-c*c)/(2*a*b));
// to find angle between M1M2 and M1P where P is the plotter position.
void FK(float l1, float l2,float &x,float &y) {
#ifdef COREXY
  l1 *= threadPerStep;
  l2 *= threadPerStep;

  x = (float)( l1 + l2 ) / 2.0;
  y = x - (float)l2;
#endif
#ifdef TRADITIONALXY
  l1 *= threadPerStep;
  l2 *= threadPerStep;
  x = l1;
  y = l2;
#endif
#ifdef POLARGRAPH2
  float a = (float)l1 * threadPerStep;
  float b = (limit_right-limit_left);
  float c = (float)l2 * threadPerStep;

  // slow, uses trig
  // we know law of cosines:   cc = aa + bb -2ab * cos( theta )
  // or cc - aa - bb = -2ab * cos( theta )
  // or ( aa + bb - cc ) / ( 2ab ) = cos( theta );
  // or theta = acos((aa+bb-cc)/(2ab));
  //x = cos(theta)*l1 + limit_left;
  //y = sin(theta)*l1 + limit_top;
  // and we know that cos(acos(i)) = i
  // and we know that sin(acos(i)) = sqrt(1-i*i)
  float theta = ((a*a+b*b-c*c)/(2.0*a*b));
  x = theta * a + limit_left;
  y = limit_top - (sqrt( 1.0 - theta * theta ) * a);
#endif
}


//------------------------------------------------------------------------------
// pause microseconds
void pause(long us) {
  delay(us/1000);
  delayMicroseconds(us%1000);
}


//------------------------------------------------------------------------------
void line(float x,float y,float z) {
  motors_engaged = true;
  long l1,l2;
  IK(x,y,l1,l2);
  long d1 = l1 - laststep1;
  long d2 = l2 - laststep2;

  long ad1=abs(d1);
  long ad2=abs(d2);
  int dir1=d1<0?M1_REEL_IN:M1_REEL_OUT;
  int dir2=d2<0?M2_REEL_IN:M2_REEL_OUT;
  long over;
  long i;

  long ad = max(ad1,ad2);
  /*
  long d = 1500;
  long accelerate_until = d - step_delay;
  long decelerate_after = ad - accelerate_until;
  if(decelerate_after < accelerate_until ) {
    decelerate_after = accelerate_until = ad/2;
  }
#if VERBOSE > 2
  Serial.print("s ");  Serial.println(ad);
  Serial.print("a ");  Serial.println(accelerate_until);
  Serial.print("d ");  Serial.println(decelerate_after);
#endif
  */

  setPenAngle((int)z);

  // bresenham's line algorithm.
  if(ad1>ad2) {
    over = ad1/2;
    for(i=0;i<ad1;++i) {
      M1_ONESTEP(dir1);
      over+=ad2;
      if(over>ad1) {
        over-=ad1;
        M2_ONESTEP(dir2);
      }

      //if(i<accelerate_until) d--;
      //if(i>=decelerate_after) d++;
      pause(step_delay);
#ifdef USE_LIMIT_SWITCH
      if(readSwitches()) return;
#endif
    }
  } else {
    over = ad2/2;
    for(i=0;i<ad2;++i) {
      M2_ONESTEP(dir2);
      over+=ad1;
      if(over>ad2) {
        over-=ad2;
        M1_ONESTEP(dir1);
      }

      //if(i<accelerate_until) d--;
      //if(i>=decelerate_after) d++;
      pause(step_delay);
#ifdef USE_LIMIT_SWITCH
      if(readSwitches()) return;
#endif
    }
  }

  laststep1=l1;
  laststep2=l2;
  // I hope this prevents rounding errors.  Small fractions of lines
  // over a long time could lead to lost steps and drawing problems.
  FK(l1,l2,posx,posy);
  posz=z;
}


//------------------------------------------------------------------------------
void line_safe(float x,float y,float z) {
  // split up long lines to make them straighter?
  float dx=x-posx;
  float dy=y-posy;
  float dz=z-posz;

  float x0=posx;
  float y0=posy;
  float z0=posz;
  float a;

  float len=sqrt(dx*dx+dy*dy);
  // too long!
  long pieces=ceil(len / MM_PER_SEGMENT);

  for(long j=1;j<pieces;++j) {
    a=(float)j/(float)pieces;

    line(dx*a+x0,
         dy*a+y0,
         dz*a+z0);
  }
  line(x,y,z);
}


//------------------------------------------------------------------------------
// This method assumes the limits have already been checked.
// This method assumes the start and end radius match.
// This method assumes arcs are not >180 degrees (PI radians)
// cx/cy - center of circle
// x/y - end position
// dir - ARC_CW or ARC_CCW to control direction of arc
void arc(float cx,float cy,float x,float y,float z,char clockwise) {
  // get radius
  float dx = posx - cx;
  float dy = posy - cy;
  float sr=sqrt(dx*dx+dy*dy);

  // find angle of arc (sweep)
  float sa=atan3(dy,dx);
  float ea=atan3(y-cy,x-cx);
  float er=sqrt(dx*dx+dy*dy);
  
  float da=ea-sa;
  if(clockwise!=0 && da<0) ea+=2*PI;
  else if(clockwise==0 && da>0) sa+=2*PI;
  da=ea-sa;
  float dr = er-sr;

  // get length of arc
  // float circ=PI*2.0*radius;
  // float len=theta*circ/(PI*2.0);
  // simplifies to
  float len1 = abs(da) * sr;
  float len = sqrt( len1 * len1 + dr * dr );

  int i, segments = ceil( len / MM_PER_SEGMENT );

  float nx, ny, nz, angle3, scale;
  float a,r;
  for(i=0;i<=segments;++i) {
    // interpolate around the arc
    scale = ((float)i)/((float)segments);

    a = ( da * scale ) + sa;
    r = ( dr * scale ) + sr;
    
    nx = cx + cos(a) * r;
    ny = cy + sin(a) * r;
    nz = ( z - posz ) * scale + posz;
    // send it to the planner
    line(nx,ny,nz);
  }
}


//------------------------------------------------------------------------------
// instantly move the virtual plotter position
// does not validate if the move is valid
void teleport(float x,float y) {
  posx=x;
  posy=y;

  // @TODO: posz?
  long L1,L2;
  IK(posx,posy,L1,L2);
  laststep1=L1;
  laststep2=L2;
}


/**
 * Print a helpful message to serial.  The first line must never be changed to play nice with the JAVA software.
 */
void help() {
  Serial.print(F("\n\nHELLO WORLD! I AM DRAWBOT #"));
  Serial.println(robot_uid);
  sayVersionNumber();
  Serial.println(F("M100 - display this message"));
  Serial.println(F("M101 [Tx.xx] [Bx.xx] [Rx.xx] [Lx.xx]"));
  Serial.println(F("       - display/update board dimensions."));
  Serial.println(F("As well as the following G-codes (http://en.wikipedia.org/wiki/G-code):"));
  Serial.println(F("G00,G01,G02,G03,G04,G28,G90,G91,G92,M18,M114"));
}


void sayVersionNumber() {
  int versionNumber = loadVersion();
  
  Serial.print(F("Firmware v"));
  Serial.println(versionNumber,DEC);
}


// touch some limit switches, then go to the home position.
void findHome() {
#ifdef USE_LIMIT_SWITCH
  Serial.println(F("Homing..."));

  motors_engaged = true;

  if(readSwitches()) {
    Serial.println(F("** ERROR **"));
    Serial.println(F("Problem: Plotter is already touching switches."));
    Serial.println(F("Solution: Please unwind the strings a bit and try again."));
    return;
  }

  int home_step_delay=300;
  int safe_out=50;

  // reel in the left motor until contact is made.
  Serial.println(F("Find left..."));
  do {
    M1_ONESTEP(M1_REEL_IN );
    M2_ONESTEP(M2_REEL_OUT);
    delayMicroseconds(home_step_delay);
  } while(!readSwitches());
  laststep1=0;

  // back off so we don't get a false positive on the next motor
  int i;
  for(i=0;i<safe_out;++i) {
    M1_ONESTEP(M1_REEL_OUT);
    delayMicroseconds(home_step_delay);
  }
  laststep1=safe_out;

  // reel in the right motor until contact is made
  Serial.println(F("Find right..."));
  do {
    M1_ONESTEP(M1_REEL_OUT);
    M2_ONESTEP(M2_REEL_IN );
    delay(step_delay);
    laststep1++;
  } while(!readSwitches());
  laststep2=0;

  // back off so we don't get a false positive that kills line()
  for(i=0;i<safe_out;++i) {
    M2_ONESTEP(M2_REEL_OUT);
    delay(step_delay);
  }
  laststep2=safe_out;

  Serial.println(F("Centering..."));
  line(homeX,homeY,posz);
#endif // USE_LIMIT_SWITCH
}


//------------------------------------------------------------------------------
void where() {
  Serial.print(F("X"));  Serial.print(posx);
  Serial.print(F(" Y"));  Serial.print(posy);
  Serial.print(F(" Z"));  Serial.print(posz);
  Serial.print(' ');  printFeedRate();
  Serial.print(F("\n"));
}


//------------------------------------------------------------------------------
void printConfig() {
  Serial.print(m1d);              Serial.print(F("="));
  Serial.print(limit_top);        Serial.print(F(","));
  Serial.print(limit_left);       Serial.print(F("\n"));
  Serial.print(m2d);              Serial.print(F("="));
  Serial.print(limit_top);        Serial.print(F(","));
  Serial.print(limit_right);      Serial.print(F("\n"));
  Serial.print(F("Bottom="));     Serial.println(limit_bottom);
  where();
}


//------------------------------------------------------------------------------
// from http://www.arduino.cc/cgi-bin/yabb2/YaBB.pl?num=1234477290/3
void EEPROM_writeLong(int ee, long value) {
  byte* p = (byte*)(void*)&value;
  for (int i = 0; i < sizeof(value); i++)
  EEPROM.write(ee++, *p++);
}


//------------------------------------------------------------------------------
// from http://www.arduino.cc/cgi-bin/yabb2/YaBB.pl?num=1234477290/3
float EEPROM_readLong(int ee) {
  long value = 0;
  byte* p = (byte*)(void*)&value;
  for (int i = 0; i < sizeof(value); i++)
  *p++ = EEPROM.read(ee++);
  return value;
}


//------------------------------------------------------------------------------
void saveUID() {
  Serial.println(F("Saving UID."));
  EEPROM_writeLong(ADDR_UUID,(long)robot_uid);
}


//------------------------------------------------------------------------------
void savePulleyDiameter() {
  EEPROM_writeLong(ADDR_PULLEY_DIA1,pulleyDiameter*10000);
  //EEPROM_writeLong(ADDR_PULLEY_DIA2,pulleyDiameter*10000);
}
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
void loop() {
  Serial_listen();

  // Puts motors to sleep after a timeout.
  // Stepper motors can draw more current when idle than in operation, causing these to potentially
  // overheat. So this will disengage the steppers after not receiving commands for a while.
  if( (millis() - last_cmd_time) > TIMEOUT_MOTORS && motors_engaged ) {
    motor_disengage();
  }

  // The PC will wait forever for the ready signal.
  // if Arduino hasn't received a new instruction in a while, send ready() again
  // just in case USB garbled ready and each half is waiting on the other.
  if( (millis() - last_ready_time) > TIMEOUT_OK ) {
    ready();
  }
}


/**
 * This file is part of makelangelo-firmware.
 *
 * makelangelo-firmware is free software: you can redistribute it and/or modify
 * it under the terms of the GNU General Public License as published by
 * the Free Software Foundation, either version 3 of the License, or
 * (at your option) any later version.
 *
 * makelangelo-firmware is distributed in the hope that it will be useful,
 * but WITHOUT ANY WARRANTY; without even the implied warranty of
 * MERCHANTABILITY or FITNESS FOR A PARTICULAR PURPOSE.  See the
 * GNU General Public License for more details.
 *
 * You should have received a copy of the GNU General Public License
 * along with Foobar.  If not, see <http://www.gnu.org/licenses/>.
 */

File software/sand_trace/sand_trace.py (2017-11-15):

#!/usr/bin/env python
# -*- coding: utf-8 -*-

import serial
import time
import random
import math


from kivy.app import App
from kivy.uix.widget import Widget
from kivy.properties import NumericProperty, ReferenceListProperty,\
    ObjectProperty
from kivy.vector import Vector
from kivy.clock import Clock


__author__ = 'Paul Chase'




class PongPaddle(Widget):
    score = NumericProperty(0)

    def bounce_ball(self, ball):
        if self.collide_widget(ball):
            vx, vy = ball.velocity
            offset = (ball.center_y - self.center_y) / (self.height / 2)
            bounced = Vector(-1 * vx, vy)
            vel = bounced * 1.1
            ball.velocity = vel.x, vel.y + offset


class PongBall(Widget):
    velocity_x = NumericProperty(0)
    velocity_y = NumericProperty(0)
    velocity = ReferenceListProperty(velocity_x, velocity_y)

    def move(self):
        self.pos = Vector(*self.velocity) + self.pos


class PongGame(Widget):
    ball = ObjectProperty(None)
    player1 = ObjectProperty(None)
    player2 = ObjectProperty(None)

    def serve_ball(self, vel=(4, 0)):
        self.ball.center = self.center
        self.ball.velocity = vel

    def update(self, dt):
        self.ball.move()

        # bounce of paddles
        self.player1.bounce_ball(self.ball)
        self.player2.bounce_ball(self.ball)

        # bounce ball off bottom or top
        if (self.ball.y < self.y) or (self.ball.top > self.top):
            self.ball.velocity_y *= -1

        # went of to a side to score point?
        if self.ball.x < self.x:
            self.player2.score += 1
            self.serve_ball(vel=(4, 0))
        if self.ball.x > self.width:
            self.player1.score += 1
            self.serve_ball(vel=(-4, 0))

    def on_touch_move(self, touch):
        if touch.x < self.width / 3:
            self.player1.center_y = touch.y
        if touch.x > self.width - self.width / 3:
            self.player2.center_y = touch.y


class PongApp(App):
    def build(self):
        game = PongGame()
        game.serve_ball()
        Clock.schedule_interval(game.update, 1.0 / 60.0)
        return game


if __name__ == '__main__':
    PongApp().run()

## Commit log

2017-09-08 Simple magnet driver
    Need to print this out to test the concept - how big of a magnet? How much sand? etc.
    [magnet_mount.stl, spring_corner.scad]
2017-09-11 All the bits for a cheap gantry.
    Thought of a way to significantly under-design it, though... so
    I'll fire that out. Might not need most of these bits :-/
    Paul
    [belt_clamp.stl, drill_guide.stl, idler_corner.stl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]
2017-09-11 Shortened up the corners, got rid of the belt guide - it didn't work well.
    [parametric_pulleys.scad, spring_corner.scad]
2017-09-14 Added corners designed to use gravity instead of springs.
    Also added a magnet mount for a bigger magnet - 1/2" cylinder by
    1/2" long. If it doesn't work we'll replace the bearing with a
    spherical magnet :-)
    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
    [half_in_magnet_mount.stl, idler_weight_corner.stl, motor_weight_corner.stl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]
2017-09-14 Initial commit of firmware example code - playing with makelangelo
    Not sure what firmware is a good starting point, but I like the
    adafruit motor shield, so probably start there.
    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
    [belt_clamp.stl, drill_guide.stl, half_in_magnet_mount.stl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]
2017-09-15 Moved the firmware, added a readme with the commands it accepts.
    [magnet_mount_1-2.stl, magnet_mount_3-8.stl]
2017-09-16 The motors spin... just really slowly. Not sure the problem.
    Debating checking out the GRBL shield/firmware... makelangelo isn't
    as nice out of box as I was hoping.
    [makelangeloFirmwareAMS.ino]
2017-09-28 Using GRBL firmware instead, with the CNC shield :-)
    Way faster, and includes jog commands.
    [config.h, cpu_map.h, defaults.h]
2017-10-02 Added GRBL firmware - alternate running system :-)
2017-10-02 Added grbl so I can muck about with it :-)
    Need to add logic to drive a polar bot.
    [config.h, cpu_map.h, defaults.h]
2017-10-04 Added polarxy support to the firmware.
    Highly experimental.
    [config.h]
2017-10-16 Deprecating the grbl branch.
    Initial plan was to add the polar code into GRBL, but there's a
    lot of hiccups there, and it's really easy to simply translate the
    gcode before sending it... so that's the plan now.
    g1 X10 Y10 will move both motors to 10mm extended - which, in a
    polar bot, isn't possible. So definitely want to revisit the
    firmware, but right now I just want to get something drawing.
2017-10-17 Added a quick python gcode sender.
    The coordinate transform doesn't work yet :-)
    [sand_trace.py]
2017-10-17 added a belt roller
    you can loop the belt back to the motor end, effectively doubling the sprung length.
    [spring_corner.scad]
2017-10-24 updating UGS
    Thoughts on homing - if the spring travel is greater, we can home X while Y is disabled.
    Then don't bother homing Y - just use the X position all the way home as (0,0).
    Y should be pulled out enough that the position is well known.
2017-11-09 re-added the sand trace
2017-11-09 Added parts to make the tensioners a 2-1 pulley, and use string instead of gt2 belts.
    [belt_pulley.stl, magnet_mount_1-2.stl, magnet_mount_3-8.stl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]
2017-11-15 added gravity_leg.scad
    [gravity_leg.scad, spring_corner.scad]
2017-11-16 gravity leg is go
    [gravity_leg.scad, gravity_leg_idler.stl, gravity_leg_motor.stl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]
2017-11-16 Updated the pulley mount, mainly.
    Added clearance, and removed clearance from the claw for the giant weight.
    [gravity_leg.scad, gravity_leg_idler.stl, gravity_leg_motor.stl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]
2017-11-27 Updated gravity leg. Printing test set!
    [gravity_leg.scad, gravity_leg_idler.stl, gravity_leg_motor.stl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]
2017-11-30 New everything :-)
    [gravity_leg.scad, gravity_leg_idler.stl, gravity_leg_motor.stl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]
2018-01-24 Adding a grbl-mod that should have decent polar support :-)
2018-02-16 Reorganized a bit, added crossbot parts
    Making a super-simple fixed-motor gantry.
    [belt_clamp.stl, belt_pulley.stl, configuration.scad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]
2018-02-27 Added more crossbot components
    [beam_carriage.stl, configuration.scad, crossbot.scad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]
2018-03-05 yay crossbot - beefed up a little
    [beam_carriage.stl, crossbot.scad, double_idler.stl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]
2018-03-05 Updated, added some holders
    [PM_UNO_base_fan_holder.stl, PM_uno_mount_fan_mod.stl, crossbot.scad]
2018-03-05 Updated crossbot STLs, added the base beam mount.
    Right now the beam mount will restrict the beam a fair bit, but gotta get something going - worried about table stability.
    [base_beam_mount.stl, double_idler.stl, magnet_carriage.stl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]
2018-03-07 updated crossbot mount
    [base_beam_mount.stl, crossbot.scad]
2018-03-08 Updated the crossbot stls - mounts are in there and functional.
    [base_beam_mount.stl, base_beam_mount_motor.stl, beam_carriage.stl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]
2018-03-14 Added newest grbl, gcode creation bits
    She works! Gcode is a bit crusty, but it can be lived with for the
    faire.
    [PDF Feature Matrix.ods, alarm_codes_en_US.csv, build_option_codes_en_US.csv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]
2018-03-14 Updated crossbot
    [crossbot.scad]
2018-03-16 Updated grbl config to take out Z HOMING_CYCLE_0 Now the machine can use its endstops!
    [config.h]
2018-03-25 Fixed config, clear
    [clear.stl]
2018-04-04 Added a glass clamp :-)
    [configuration.scad, glass_clamp_base.stl, glass_clamp_lever.stl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]
2018-04-06 updated the glass clamps - first design was before measuring anything :-)
    [configuration.scad, glass_clamp.stl, glass_clamps.scad]
2018-04-12 Added new idler and motor mounts - under beta
    [crossbot.scad, idler_mount_2.stl, motor_mount_2.stl]
2018-04-13 Added cross bits, updated small set
    [cross_idler.stl, cross_motor.stl, crossbot.scad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]
2018-04-17 updated cross ends - but need to redo
    Move motor down, get the belt into the very bottom of the slot
    to avoid rubbing :-)
    [cross_idler.stl, cross_motor.stl, crossbot.scad]
2018-04-17 Went the other way with the belt align
    [cross_idler.stl, cross_motor.stl, crossbot.scad]
2018-04-20 Added holes so you can get the belt in :-)
    [cross_idler.stl, cross_motor.stl, crossbot.scad]
2018-04-20 updated the roundel
    [crossbot.scad, pimoroni_template.scad, roundel.stl]
2018-04-22 stripped and strengthened the magnet carriage
    [crossbot.scad, tri-carriage.stl]
2018-05-06 Updated mounts.
    Coming soon: arduino/pi mount.
    [arduino_mount.stl, glass_clamp.stl, glass_clamps.scad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]
2018-05-16 Electronics plate.
    todo: add fan mount to the arduino case
    todo: add mount for dc-dc converter
    todo: add zip tie holes/ wire securement
    converter lugs are 52mm apart, 4mm wide.
    [arduino_sled.stl, electronics_plate.scad]
2018-05-21 final electronics plate
    [electronics_plate.scad, electronics_plate.stl]

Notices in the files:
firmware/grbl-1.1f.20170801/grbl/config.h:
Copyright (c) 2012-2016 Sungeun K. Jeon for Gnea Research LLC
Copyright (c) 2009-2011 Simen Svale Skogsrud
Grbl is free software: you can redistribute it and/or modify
